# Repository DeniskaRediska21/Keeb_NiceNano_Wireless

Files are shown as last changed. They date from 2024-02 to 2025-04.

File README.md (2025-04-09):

# Split Ergo Ortholinear Hotswap Keyboard based on supermini_nrf52840 (NiceNano clone) with Choc switches

This project attempts to create easelly reproducible split ortholinear hotswap mechanical
keyboard. 

Gimmics: 
+ This design doesn't require any diodes
+ Uses supermini_nrf52840 as MC, runs on CircuitPython
+ Key layouts are changed by dragging a file onto MC's storrage
+ Halves are connected through BLE
+ Conencts to PC through both BLE and wire
+ PCB fits into 100x100mm square, so it is very cheap to order from Chineese manifacturers
+ Uses Choc switches

# Gallery

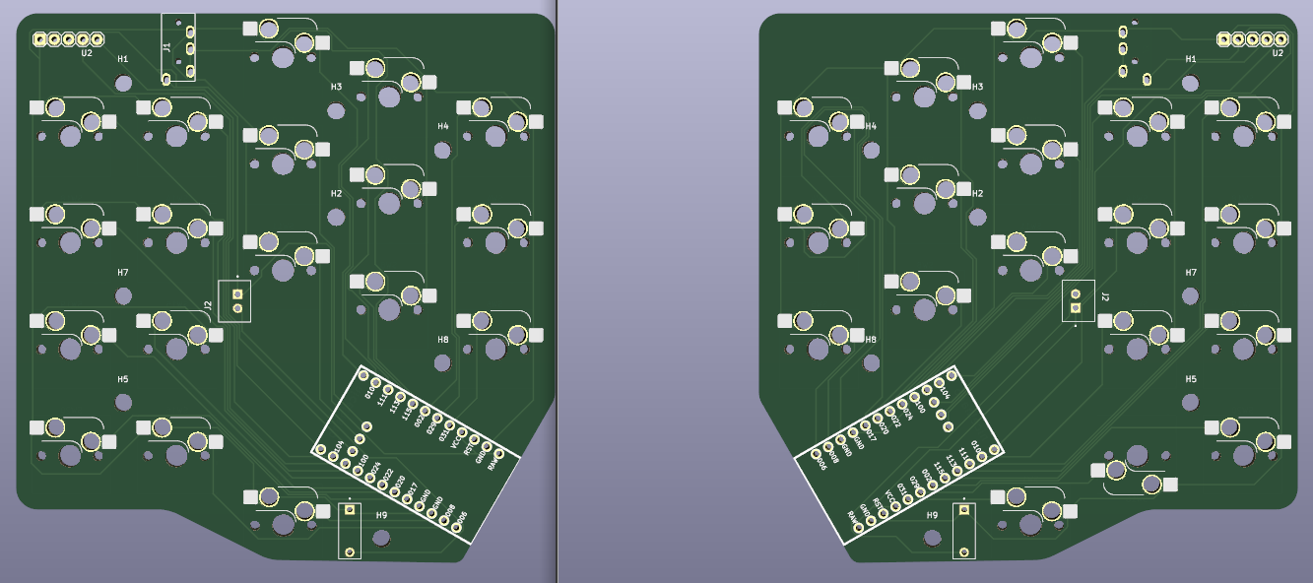
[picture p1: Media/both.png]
PCB


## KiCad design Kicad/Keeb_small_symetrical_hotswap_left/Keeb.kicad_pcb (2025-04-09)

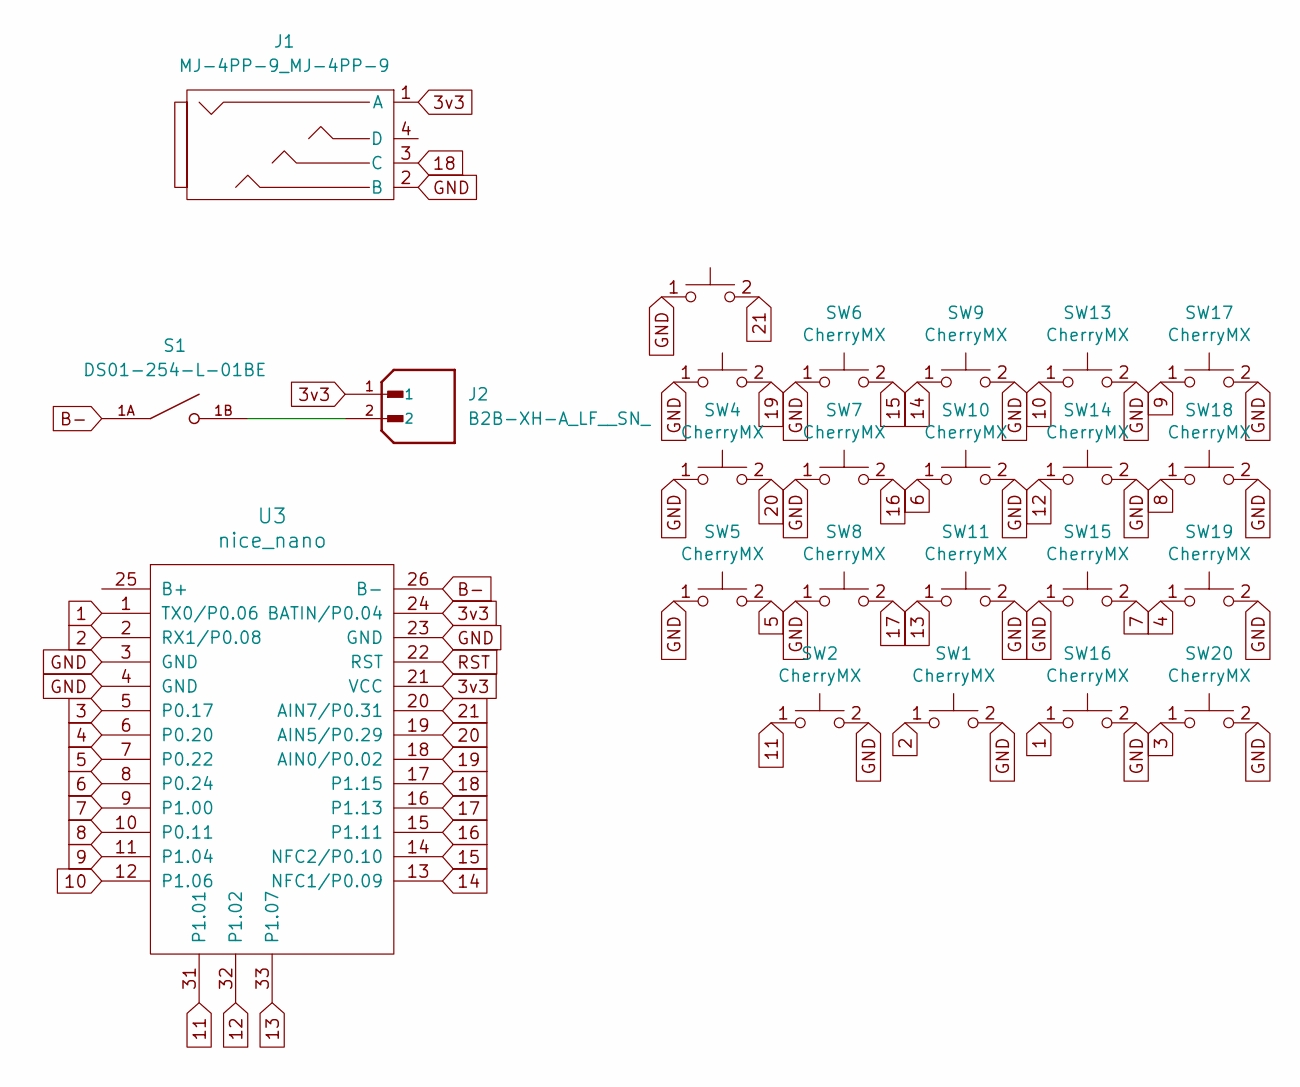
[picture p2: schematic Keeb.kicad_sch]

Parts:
J1: MJ-4PP-9_MJ-4PP-9; MJ-4PP-9
J2: B2B-XH-A_LF__SN_; JST_B2B-XH-A_LF__SN_; PARTREV N/A
S1: DS01-254-L-01BE; SW_DS01-254-L-01BE; PARTREV 1.0
SW1, SW2, SW3, SW4, SW5, SW6, SW7, SW8, SW9, SW10, SW11, SW12, SW13, SW14, SW15, SW16, SW17, SW18, SW19, SW20: CherryMX; Hotswap_Choc_V1_Plated_1.00u
U3: nice_nano

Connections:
1: SW16.1, U3.1 (TX0/P0.06)
2: SW1.1, U3.2 (RX1/P0.08)
3: SW20.1, U3.5 (P0.17)
3v3: J1.1 (A), J2.1, U3.21 (VCC), U3.24 (BATIN/P0.04)
4: SW19.1, U3.6 (P0.20)
5: SW5.2, U3.7 (P0.22)
6: SW10.1, U3.8 (P0.24)
7: SW15.2, U3.9 (P1.00)
8: SW18.1, U3.10 (P0.11)
9: SW17.1, U3.11 (P1.04)
10: SW13.1, U3.12 (P1.06)
11: SW2.1, U3.31 (P1.01)
12: SW14.1, U3.32 (P1.02)
13: SW11.1, U3.33 (P1.07)
14: SW9.1, U3.13 (NFC1/P0.09)
15: SW6.2, U3.14 (NFC2/P0.10)
16: SW7.2, U3.15 (P1.11)
17: SW8.2, U3.16 (P1.13)
18: J1.3 (C), U3.17 (P1.15)
19: SW3.2, U3.18 (AIN0/P0.02)
20: SW4.2, U3.19 (AIN5/P0.29)
21: SW12.2, U3.20 (AIN7/P0.31)
B-: S1.1A, U3.26 (B-)
GND: J1.2 (B), SW1.2, SW2.2, SW3.1, SW4.1, SW5.1, SW6.1, SW7.1, SW8.1, SW9.2, SW10.2, SW11.2, SW12.1, SW13.2, SW14.2, SW15.1, SW16.2, SW17.2, SW18.2, SW19.2, SW20.2, U3.3 (GND), U3.4 (GND), U3.23 (GND)
unnamed: J2.2, S1.1B
RST: U3.22 (RST)

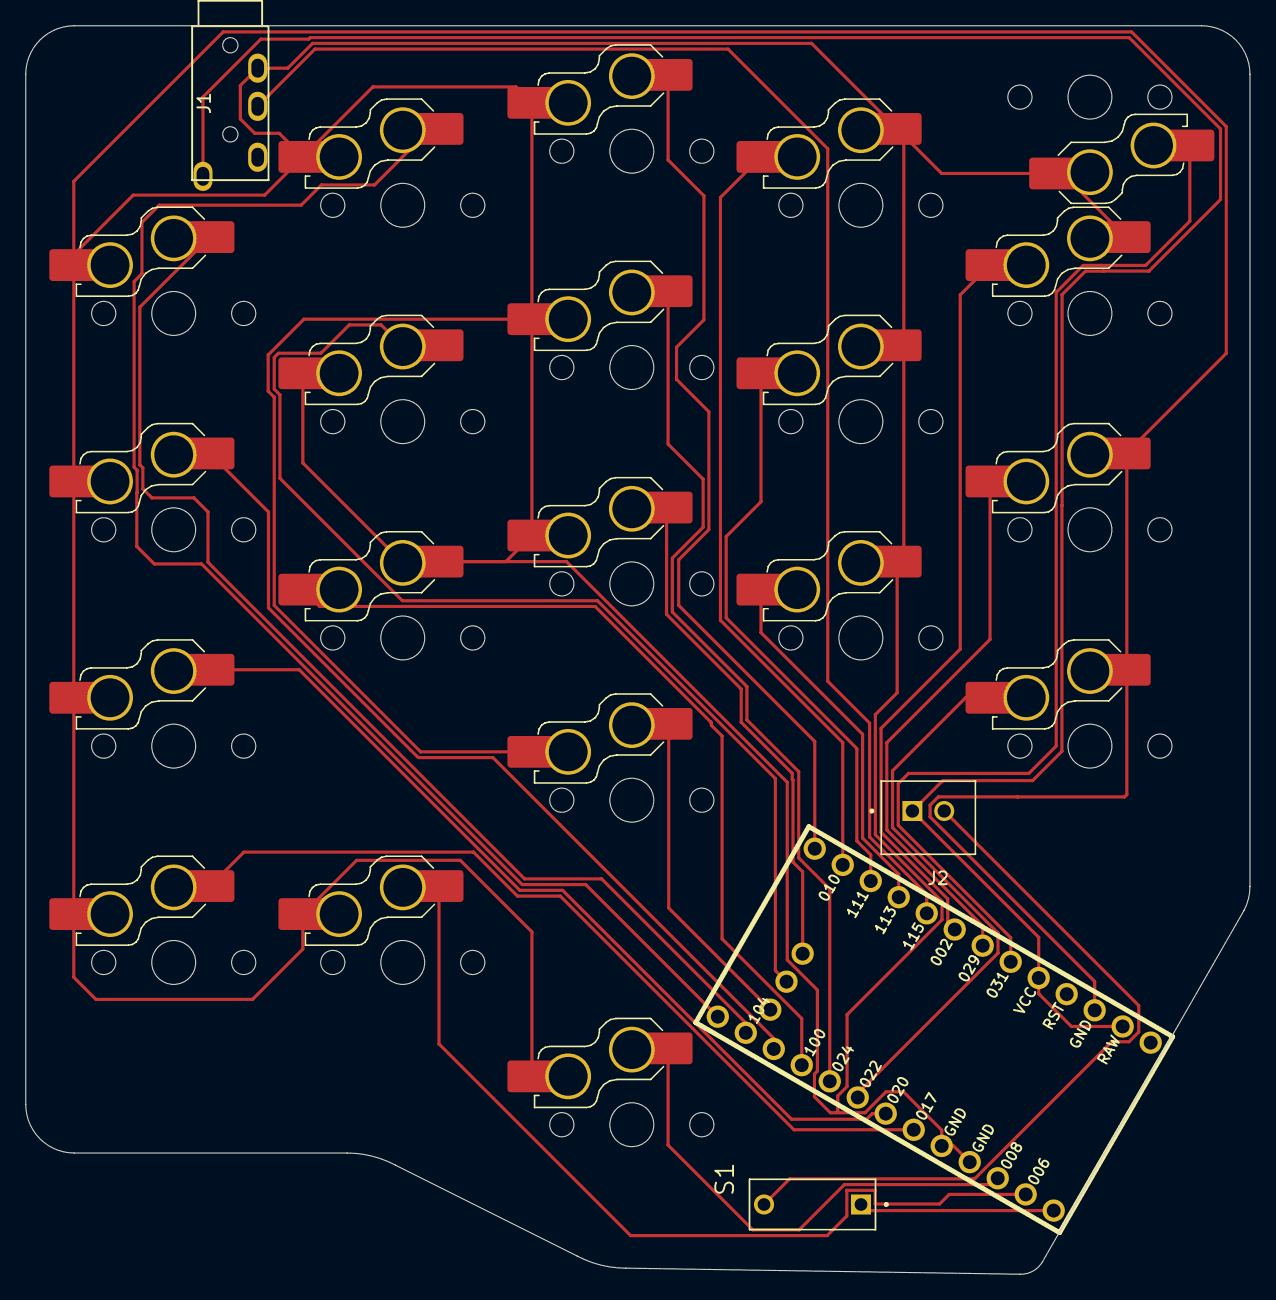
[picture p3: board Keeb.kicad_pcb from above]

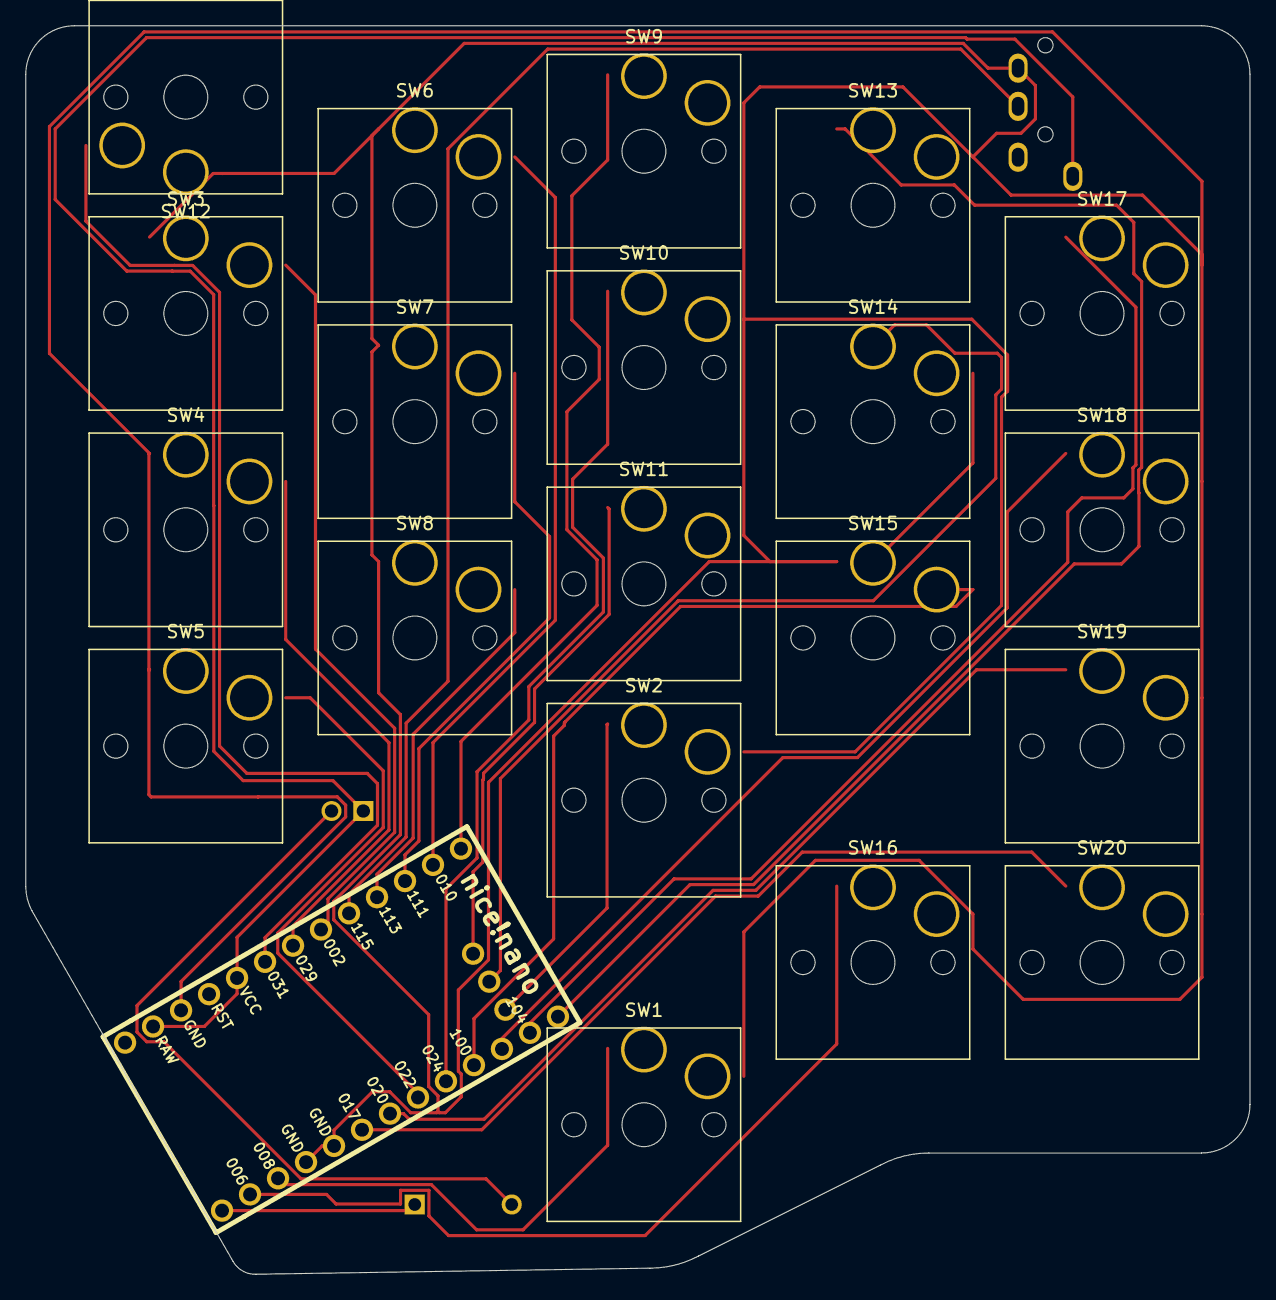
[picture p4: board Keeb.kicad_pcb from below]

Board: 2 copper layers, 96.2 x 98.1 mm, 24 parts (21 on the bottom side), 25 nets.

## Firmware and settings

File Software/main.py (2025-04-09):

import board
import digitalio 
from kb import KMKKeyboard, isRight
from storage import getmount
from kmk.keys import KC, Key
from kmk.modules.layers import Layers
from kmk.modules.split import Split, SplitSide, SplitType
from kmk.hid import HIDModes

import supervisor

WIRED = supervisor.runtime.usb_connected
keyboard = KMKKeyboard()

keyboard.tap_time = 100

layers = Layers()


split_side = SplitSide.RIGHT if isRight else SplitSide.LEFT

print('Right' if isRight else 'Left')

split = Split(
    split_type=SplitType.BLE,
    split_side=split_side,
)

keyboard.modules = [layers, split]

LOWER =KC.MO(1)
RAISE =KC.MO(2)

keyboard.keymap = [

    [  #QWERTY
                                            KC.RALT,			             KC.TAB,\

        KC.Q,    KC.W,    KC.E,    KC.R,    KC.T,                        KC.Y,      KC.U,    KC.I,    KC.O, KC.P,\

        KC.A,    KC.S,    KC.D,    KC.F,    KC.G,                        KC.H,      KC.J,    KC.K,    KC.L, KC.BSPC,\

        KC.Z,    KC.X,    KC.C,    KC.V,    KC.COMM,                     KC.DOT,    KC.N,    KC.M,    KC.B, KC.ESC,\
                                            
                          KC.NO, 				                                             KC.NO,\

                          KC.LSHIFT,   LOWER, KC.SPACE,              		 KC.ENT, RAISE,   KC.LCTRL,
                                                    

    ],

    [  #LOWER	
                                           					                           KC.NO, 			                KC.NO,\

        KC.N1,          KC.N2,           KC.N3,           	     KC.N4,                KC.N5,                           KC.N6,      KC.N7,     KC.N8,     KC.N9,    KC.N0,\

        KC.LCTL(KC.A),  KC.LCTL(KC.S),   KC.LCTL(KC.RALT(KC.T)), KC.QUES,              KC.LCTL(KC.V),                   KC.N0,      KC.LEFT,   KC.DOWN,   KC.UP,    KC.RIGHT,\

        KC.LCTL(KC.Z),  KC.LCTL(KC.X),   KC.LCTL(KC.INSERT),     KC.LSFT(KC.INSERT),   KC.LCTL(KC.C),                   KC.GRAVE,   KC.LABK,   KC.PIPE,   KC.RABK,  KC.SLSH,\
                                                                                       
                                         KC.BT_NXT, 				                                                                               KC.BT_PRV,\
 
                                         KC.LSHIFT,                  KC.NO,                KC.SPACE,                        KC.ENT,     KC.NO,     KC.LCTRL,
    ],

    [  #RAISE
                                              KC.NO,			    KC.NO,\

        KC.EXLM,   KC.AT, KC.HASH,  KC.DLR,   KC.PERC,                      KC.CIRC, KC.AMPR, KC.ASTR, KC.LPRN, KC.RPRN,\

        KC.F2,     KC.F5,   KC.F9,  KC.QUOT,  KC.SCLN,                      KC.UNDS,  KC.EQL, KC.LCBR, KC.RCBR, KC.DEL,\

        KC.F12,    KC.F11,  KC.F10, KC.DQUO,  KC.COLON,                     KC.MINS, KC.PLUS, KC.LBRC, KC.RBRC, KC.BSLS,\

                            KC.NO, 				                                              KC.NO,\

                          KC.LSHIFT,   KC.NO,   KC.SPACE,                       KC.ENT,      KC.NO,    KC.LCTRL,
    ]

]


if __name__ == '__main__':
    if isRight or WIRED:
        keyboard.go()
    else:
        keyboard.go(hid_type=HIDModes.BLE, ble_name='Keeb')

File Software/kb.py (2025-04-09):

import board
import digitalio

from storage import getmount

import kmk
from kmk import kmk_keyboard
from kmk.kmk_keyboard import KMKKeyboard as _KMKKeyboard
from kmk.scanners.keypad import KeysScanner
from kmk.scanners.encoder import RotaryioEncoder

name = str(getmount('/').label)
isRight = True if name.endswith('R') else False

# GPIO to key mapping, Left
_KEY_CFG_LEFT = [
board.P0_31,
board.P0_02,board.P0_10,board.P0_09,board.P1_06,board.P1_04,
board.P0_29,board.P1_11,board.P0_24,board.P1_02,board.P0_11,
board.P0_22,board.P1_13,board.P1_07,board.P1_00,board.P0_20,
board.P1_01,
board.P0_08,board.P0_06,board.P0_17,
]

# GPIO to key mapping, Right
_KEY_CFG_RIGHT = [
board.P1_01,
board.P1_13,board.P1_02,board.P1_04,board.P0_24,board.P0_17,
board.P1_11,board.P0_09,board.P0_11,board.P0_22,board.P0_08,
board.P1_15,board.P0_10,board.P1_00,board.P0_20,board.P0_06,
board.P1_07,
board.P0_31,board.P0_29,board.P0_02,
]

class KMKKeyboard(_KMKKeyboard):
    def __init__(self):
        # create and register the scanner
        self.matrix = KeysScanner(
            pins=_KEY_CFG_RIGHT if isRight else _KEY_CFG_LEFT,
            value_when_pressed=False,
            pull=True,
            interval=0.02,
            max_events=64
        )

    coord_mapping = [
                         0,   20,
         1,  2,  3,  4,  5,   21, 22, 23, 24, 25,
         6,  7,  8,  9, 10,   26, 27, 28, 29, 30,
        11, 12, 13, 14, 15,   31, 32, 33, 34, 35,
                16,                   36,
                17, 18, 19,   37, 38, 39
    ]

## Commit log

2025-04-09 current version, all problems fixed, software compiled for CP 9.0
    [Keeb-B_Cu.gbr, Keeb-B_Mask.gbr, Keeb-Edge_Cuts.gbr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]
2025-04-12 Work on gaskets started, now need to create laser files
